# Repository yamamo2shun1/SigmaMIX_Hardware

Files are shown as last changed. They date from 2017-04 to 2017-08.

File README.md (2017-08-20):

# SigmaMIX
The SigmaMIX is a DSP/BLE board for Turntablist/Portablist, and it's an Open Source Hardware.

# Firmware/Software Repository
* [SigmaMIX Firmware for SiLabs BGM113](https://github.com/tkrworks/SigmaMIX_Firmware)  
* [SigmaMIX Remote App for Android](https://github.com/tkrworks/SigmaMIX_Remote)

**I made sure to be able to control two ADAU1701 from the BGM113 via I2C on June 7 2017!!!**

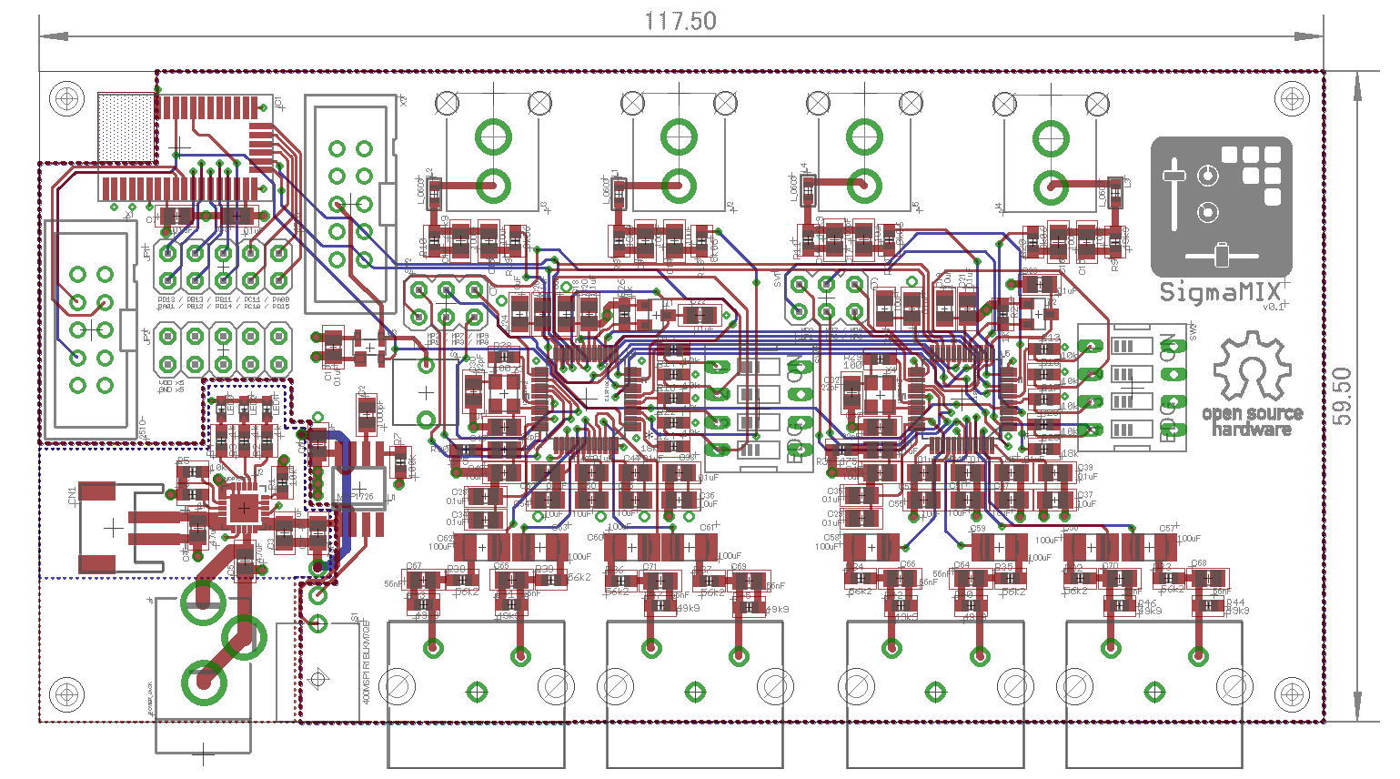
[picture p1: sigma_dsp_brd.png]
SigmaMIX Board

SigmaMIX PCB

## Test Video
[Delay Test](https://www.instagram.com/p/BXrRHsZBKkE/)  
[Effect and Scratch DEMO](https://www.instagram.com/p/BXWzQCQBJe1/)  
[Phono and Line inputs Mix and Fader Cutting Test](https://www.instagram.com/p/BV4aKTPhfiU/)  
[3-Band EQ Test via BLE](https://www.instagram.com/p/BVq-pJHB9hm/)  
[Phono EQ Test](https://www.instagram.com/p/BVVsefTBJXY/)  
[Beat and Sine Tone Test](https://www.instagram.com/p/BVFF-J9hF4o/)  
[First Scratch Test](https://www.instagram.com/p/BUi_Y2OhvBm/)  

## SPEC
* DSP: ANALOG DEVICES SigmaDSP [ADAU1701](http://www.analog.com/jp/products/processors-dsp/sigmadsp-audio-processors/adau1701.html) x2
* BLE: Silicon Labs [BGM113](http://jp.silabs.com/products/wireless/bluetooth/bluetooth-low-energy-modules/bgm113-bluetooth-low-energy-module)
* Audio: RCA Input x4 and RCA Output x8
* Power: ONLY 5-16V input [MIC39101](http://www.microchip.com/wwwproducts/en/MIC39100).
* Size: 112.0mm x 59.5mm

## HARDWARE LICENSE
<br /><span xmlns:dct="http://purl.org/dc/terms/" property="dct:title">SigmaMIX</span> by <span xmlns:cc="http://creativecommons.org/ns#" property="cc:attributionName">Shunichi Yamamoto</span> is licensed under a <a rel="license" href="http://creativecommons.org/licenses/by-sa/4.0/">Creative Commons Attribution-ShareAlike 4.0 International License</a>.

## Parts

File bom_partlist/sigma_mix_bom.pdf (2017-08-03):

Part | Value | Package | Description | Digikey
C1 | 1uF | 2012 | Multilayer Ceramic Capacitor | 490-1691-1-ND
C2 | 10uF | 2012 | Tantalum Capacitor | 478-8115-1-ND
C3 | 0.1uF | 2012 | Multilayer Ceramic Capacitor | 490-1683-6-ND
C4 | 0.1uF | 2012 | Multilayer Ceramic Capacitor | 490-1683-6-ND
C5 | 0.1uF | 2012 | Multilayer Ceramic Capacitor | 490-1683-6-ND
C6 | 10uF | 2012 | Tantalum Capacitor | 478-8115-1-ND
C7 | 0.1uF | 2012 | Multilayer Ceramic Capacitor | 490-1683-6-ND
C8 | 0.1uF | 2012 | Multilayer Ceramic Capacitor | 490-1683-6-ND
C9 | 100uF | 3528 | Tantalum Capacitor | 718-1313-1-ND
C10 | 10uF | 2012 | Multilayer Ceramic Capacitor | 490-3905-1-ND
C11 | 10uF | 2012 | Tantalum Capacitor | 478-8115-1-ND
C12 | 0.1uF | 2012 | Multilayer Ceramic Capacitor | 490-1683-6-ND
C13 | 0.1uF | 2012 | Multilayer Ceramic Capacitor | 490-1683-6-ND
C14 | 0.1uF | 2012 | Multilayer Ceramic Capacitor | 490-1683-6-ND
C15 | 10uF | 2012 | Tantalum Capacitor | 478-8115-1-ND
C16 | 0.1uF | 2012 | Multilayer Ceramic Capacitor | 490-1683-6-ND
C17 | 0.1uF | 2012 | Multilayer Ceramic Capacitor | 490-1683-6-ND
C18 | 10uF | 2012 | Multilayer Ceramic Capacitor | 490-3905-1-ND
C19 | 0.1uF | 2012 | Multilayer Ceramic Capacitor | 490-1683-6-ND
C20 | 10uF | 2012 | Multilayer Ceramic Capacitor | 490-3905-1-ND
C21 | 0.1uF | 2012 | Multilayer Ceramic Capacitor | 490-1683-6-ND
C22 | 10uF | 2012 | Multilayer Ceramic Capacitor | 490-3905-1-ND
C23 | 100uF | 3528 | Tantalum Capacitor | 718-1313-1-ND
C24 | 56nF | 2012 | Multilayer Ceramic Capacitor | 490-1662-1-ND
C25 | 3.3nF | 2012 | Multilayer Ceramic Capacitor | 399-1153-1-ND
C26 | 10uF | 2012 | Multilayer Ceramic Capacitor | 490-3905-1-ND
C27 | 100pF | 2012 | Multilayer Ceramic Capacitor | 490-1615-1-ND
C28 | 100pF | 2012 | Multilayer Ceramic Capacitor | 490-1615-1-ND
C29 | 100uF | 3528 | Tantalum Capacitor | 718-1313-1-ND
C30 | 100uF | 3528 | Tantalum Capacitor | 718-1313-1-ND
C31 | 56nF | 2012 | Multilayer Ceramic Capacitor | 490-1662-1-ND
C32 | 56nF | 2012 | Multilayer Ceramic Capacitor | 490-1662-1-ND
C33 | 56nF | 2012 | Multilayer Ceramic Capacitor | 490-1662-1-ND
C34 | 56nF | 2012 | Multilayer Ceramic Capacitor | 490-1662-1-ND
C35 | 0.1uF | 2012 | Multilayer Ceramic Capacitor | 490-1683-6-ND
C36 | 0.1uF | 2012 | Multilayer Ceramic Capacitor | 490-1683-6-ND
C37 | 10uF | 2012 | Tantalum Capacitor | 478-8115-1-ND
C38 | 0.1uF | 2012 | Multilayer Ceramic Capacitor | 490-1683-6-ND

C39 | 100uF | 3528 | Tantalum Capacitor | 718-1313-1-ND
C40 | 10uF | 2012 | Multilayer Ceramic Capacitor | 490-3905-1-ND
C41 | 10uF | 2012 | Tantalum Capacitor | 478-8115-1-ND
C42 | 0.1uF | 2012 | Multilayer Ceramic Capacitor | 490-1683-6-ND
C43 | 0.1uF | 2012 | Multilayer Ceramic Capacitor | 490-1683-6-ND
C44 | 0.1uF | 2012 | Multilayer Ceramic Capacitor | 490-1683-6-ND
C45 | 10uF | 2012 | Tantalum Capacitor | 478-8115-1-ND
C46 | 0.1uF | 2012 | Multilayer Ceramic Capacitor | 490-1683-6-ND
C47 | 0.1uF | 2012 | Multilayer Ceramic Capacitor | 490-1683-6-ND
C48 | 10uF | 2012 | Multilayer Ceramic Capacitor | 490-3905-1-ND
C49 | 0.1uF | 2012 | Multilayer Ceramic Capacitor | 490-1683-6-ND
C50 | 10uF | 2012 | Multilayer Ceramic Capacitor | 490-3905-1-ND
C51 | 0.1uF | 2012 | Multilayer Ceramic Capacitor | 490-1683-6-ND
C52 | 10uF | 2012 | Multilayer Ceramic Capacitor | 490-3905-1-ND
C53 | 100uF | 3528 | Tantalum Capacitor | 718-1313-1-ND
C54 | 56nF | 2012 | Multilayer Ceramic Capacitor | 490-1662-1-ND
C55 | 3.3nF | 2012 | Multilayer Ceramic Capacitor | 399-1153-1-ND
C56 | 10uF | 2012 | Multilayer Ceramic Capacitor | 490-3905-1-ND
C57 | 100pF | 2012 | Multilayer Ceramic Capacitor | 490-1615-1-ND
C58 | 100pF | 2012 | Multilayer Ceramic Capacitor | 490-1615-1-ND
C59 | 100uF | 3528 | Tantalum Capacitor | 718-1313-1-ND
C60 | 100uF | 3528 | Tantalum Capacitor | 718-1313-1-ND
C61 | 56nF | 2012 | Multilayer Ceramic Capacitor | 490-1662-1-ND
C62 | 56nF | 2012 | Multilayer Ceramic Capacitor | 490-1662-1-ND
C63 | 56nF | 2012 | Multilayer Ceramic Capacitor | 490-1662-1-ND
C64 | 56nF | 2012 | Multilayer Ceramic Capacitor | 490-1662-1-ND
IC1 | BGM113 | LGA Module | Bluetooth Module | 336-3817-1-ND
J1 | DC_JACK | Through Hole | Power Connector | | 未実装
J2 | RCA2_JACK | Through Hole | Audio Connector | CP-1435-ND | 未実装
J3 | RCA_JACK | Through Hole | Audio Connector | CP-1419-ND | 未実装
J4 | RCA_JACK | Through Hole | Audio Connector | CP-1420-ND | 未実装
J5 | RCA2_JACK | Through Hole | Audio Connector | CP-1435-ND | 未実装
J6 | RCA2_JACK | Through Hole | Audio Connector | CP-1435-ND | 未実装
J7 | RCA_JACK | Through Hole | Audio Connector | CP-1419-ND | 未実装
J8 | RCA_JACK | Through Hole | Audio Connector | CP-1420-ND | 未実装
J9 | RCA2_JACK | Through Hole | Audio Connector | CP-1435-ND | 未実装
JP1 | 2x5 | Through Hole | Pin Header | | 未実装
JP2 | 2x6 | Through Hole | Pin Header | | 未実装
JP3 | 2x6 | Through Hole | Pin Header | 未実装

L1 | 600ohm@100MHz | 1608 | Ferrite Beads | 490-14396-1-ND
L2 | 600ohm@100MHz | 1608 | Ferrite Beads | 490-14396-1-ND
L3 | 600ohm@100MHz | 1608 | Ferrite Beads | 490-14396-1-ND
L4 | 600ohm@100MHz | 1608 | Ferrite Beads | 490-14396-1-ND
LED1 | GREEN | 3216 | LED | 67-1002-1-ND
LED2 | RED | 3216 | LED | 67-1003-1-ND
R1 | 100k | 1608 | Resistor | P100KHCT-ND
R2 | 562 | 1608 | Resistor | P562HCT-ND
R3 | 1k | 1608 | Resistor | P1.00KHCT-ND
R4 | 10k | 1608 | Resistor | P10.0KHCT-ND
R5 | 56R2 | 1608 | Resistor | P56.2HCT-ND
R6 | 8k06 | 1608 | Resistor | P8.06KHCT-ND
R7 | 56R2 | 1608 | Resistor | P56.2HCT-ND
R8 | 8k06 | 1608 | Resistor | P8.06KHCT-ND
R9 | 56R2 | 1608 | Resistor | P56.2HCT-ND
R10 | 49k9 | 1608 | Resistor | P49.9KHCT-ND
R11 | 49k9 | 1608 | Resistor | P49.9KHCT-ND
R12 | 18k | 1608 | Resistor | P18.0KHCT-ND
R13 | 475 | 1608 | Resistor | P475HCT-ND
R14 | 56R2 | 1608 | Resistor | P56.2HCT-ND
R15 | 49k9 | 1608 | Resistor | P49.9KHCT-ND
R16 | 49k9 | 1608 | Resistor | P49.9KHCT-ND
R17 | 49k9 | 1608 | Resistor | P49.9KHCT-ND
R18 | 49k9 | 1608 | Resistor | P49.9KHCT-ND
R19 | 10k | 1608 | Resistor | P10.0KHCT-ND
R20 | 10k | 1608 | Resistor | P10.0KHCT-ND
R21 | 10k | 1608 | Resistor | P10.0KHCT-ND
R22 | 10k | 1608 | Resistor | P10.0KHCT-ND
R23 | 0 | 1608 | Resistor | P0.0ACT-ND
R24 | 1k | 1608 | Resistor | P1.00KHCT-ND
R25 | 56R2 | 1608 | Resistor | P56.2HCT-ND
R26 | 8k06 | 1608 | Resistor | P8.06KHCT-ND
R27 | 56R2 | 1608 | Resistor | P56.2HCT-ND
R28 | 8k06 | 1608 | Resistor | P8.06KHCT-ND
R29 | 56R2 | 1608 | Resistor | P56.2HCT-ND
R30 | 49k9 | 1608 | Resistor | P49.9KHCT-ND
R31 | 49k9 | 1608 | Resistor | P49.9KHCT-ND
R32 | 18k | 1608 | Resistor | P18.0KHCT-ND
R33 | 475 | 1608 | Resistor | P475HCT-ND

R34 | 56R2 | 1608 | Resistor | P56.2HCT-ND
R35 | 49k9 | 1608 | Resistor | P49.9KHCT-ND
R36 | 49k9 | 1608 | Resistor | P49.9KHCT-ND
R37 | 49k9 | 1608 | Resistor | P49.9KHCT-ND
R38 | 49k9 | 1608 | Resistor | P49.9KHCT-ND
R39 | 10k | 1608 | Resistor | P10.0KHCT-ND
R40 | 10k | 1608 | Resistor | P10.0KHCT-ND
R41 | 10k | 1608 | Resistor | P10.0KHCT-ND
R42 | 10k | 1608 | Resistor | P10.0KHCT-ND
R43 | 562 | 1608 | Resistor | P562HCT-ND
S1 | ROCKER SW | Through Hole | Switch | EG4328-ND | 未実装
S2 | TACTILE SW | Through Hole | Switch | EG4328-ND | 未実装
SV1 | 2x3 | Through Hole | Pin Header | | 未実装
SV2 | 2x3 | Through Hole | Pin Header | | 未実装
SW1 | DIP SW | Through Hole | Switch | SW1194-ND | 未実装
SW2 | DIP SW | Through Hole | Switch | SW1194-ND | 未実装
T1 | PNP | SOT-23 | Transistor | ZXTP25040DFHCT-ND
T2 | PNP | SOT-23 | Transistor | ZXTP25040DFHCT-ND
U1 | MIC39101 | SOIC8 | Power Regulator IC | 576-1782-5-ND
U2 | ADM811 | SOT-143 | Reset IC | ADM811TARTZ-REEL7CT-ND
U3 | ADAU1701 | LQFP48 | DSP IC | ADAU1701JSTZ-RLCT-ND
U4 | ADAU1701 | LQFP48 | DSP IC | ADAU1701JSTZ-RLCT-ND
X1 | SWD Interface | Through Hole | Connector | MHC20K-ND | 未実装
X2 | USBi | Through Hole | Connector | MHC10K-ND | 未実装
Y1 | 12.28MHz | SMD | Crystal Oscillator | SER4107CT-ND

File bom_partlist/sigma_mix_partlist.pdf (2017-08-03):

Part | Value | Package | Num | Description | Digikey
C3, C4, C5, C7, C8, C12, C13, C14, C16, C17, C19, C21,C35, C36, C38, C42, C43, C44, C46, C47, C49, C51 | 0.1uF | 2012 | 22 | Multilayer Ceramic Capacitor | 490-1683-6-ND
C27, C28, C57, C58 | 100pF | 2012 | 4 | Multilayer Ceramic Capacitor | 490-1615-1-ND
C9, C23, C29, C30, C39, C53, C59, C60 | 100uF | 3528 | 8 | Tantalum Capacitor | 718-1313-1-ND
C2, C6, C11, C15, C37, C41, C45 | 10uF | 2012 | 7 | Tantalum Capacitor | 478-8115-1-ND
C10, C18, C20, C22, C26, C40, C48, C50, C52, C56 | 10uF | 2012 | 10 | Multilayer Ceramic Capacitor | 490-3905-1-ND
C1 | 1uF | 2012 | 1 | Multilayer Ceramic Capacitor | 490-1691-1-ND
C25, C55 | 3.3nF | 2012 | 2 | Multilayer Ceramic Capacitor | 399-1153-1-ND
C24, C31, C32, C33, C34, C54, C61, C62, C63, C64 | 56nF | 2012 | 10 | Multilayer Ceramic Capacitor | 490-1662-1-ND
IC1 | BGM113 | LGA Module | 1 | Bluetooth Module | 336-3817-1-ND
J1 | DC_JACK | Through Hole | 1 | Power Connector | | 未実装
J2, J5, J6, J9 | RCA2_JACK | Through Hole | 4 | Audio Connector | CP-1435-ND | 未実装
J3, J4, J7, J8 | RCA_JACK | Through Hole | 2 | Audio Connector | CP-1419-ND | 未実装
JP1 | 2x5 | Through Hole | 1 | Pin Header | | 未実装
JP2, JP3 | 2x6 | Through Hole | 2 | Pin Header | | 未実装
L1, L2, L3, L4 | 600ohm@100MHz | 1608 | 4 | Ferrite Beads | 490-14396-1-ND
LED1 | GREEN | 3216 | 1 | LED | 67-1002-1-ND
LED2 | RED | 3216 | 1 | LED | 67-1003-1-ND
R1 | 100k | 1608 | 1 | Resistor | P100KHCT-ND
R23 | 0 | 1608 | 1 | Resistor | P0.0ACT-ND
R13, R33 | 475 | 1608 | 2 | Resistor | P475HCT-ND
R2, R43 | 562 | 1608 | 2 | Resistor | P562HCT-ND
R4, R19, R20, R21, R22, R39, R40, R41, R42 | 10k | 1608 | 9 | Resistor | P10.0KHCT-ND
R12, R32 | 18k | 1608 | 2 | Resistor | P18.0KHCT-ND
R3, R24 | 1k | 1608 | 2 | Resistor | P1.00KHCT-ND
R10, R11, R15, R16, R17, R18, R30, R31, R35, R36, R37, R38 | 49k9 | 1608 | 12 | Resistor | P49.9KHCT-ND
R5, R7, R9, R14, R25, R27, R29, R34 | 56R2 | 1608 | 8 | Resistor | P56.2HCT-ND
R6, R8, R26, R28 | 8k06 | 1608 | 4 | Resistor | P8.06KHCT-ND
S1 | ROCKER SW | Through Hole | 1 | Switch | EG4328-ND | 未実装
S2 | TACTILE SW | Through Hole | 1 | Switch | EG4328-ND | 未実装
SV1, SV2 | 2x3 | Through Hole | 2 | Pin Header | | 未実装
SW1, SW2 | DIP SW | Through Hole | 2 | Switch | SW1194-ND | 未実装
T1, T2 | PNP | SOT-23 | 2 | Transistor | ZXTP25040DFHCT-ND
U1 | MIC39101 | SOIC8 | 1 | Power Regulator IC | 576-1782-5-ND
U2 | ADM811 | SOT-143 | 1 | Reset IC | ADM811TARTZ-REEL7CT-ND
U3, U4 | ADAU1701 | LQFP48 | 2 | DSP IC | ADAU1701JSTZ-RLCT-ND
X1 | SWD Interface | Through Hole | 1 | Connector | MHC20K-ND | 未実装
X2 | USBi | Through Hole | 1 | Connector | MHC10K-ND | 未実装
Y1 | 12.28MHz | SMD | 1 | Crystal Oscillator | SER4107CT-ND

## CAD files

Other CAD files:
jig/SigmaMIX_Jig.dwg

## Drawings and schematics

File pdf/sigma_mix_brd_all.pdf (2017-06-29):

112.00

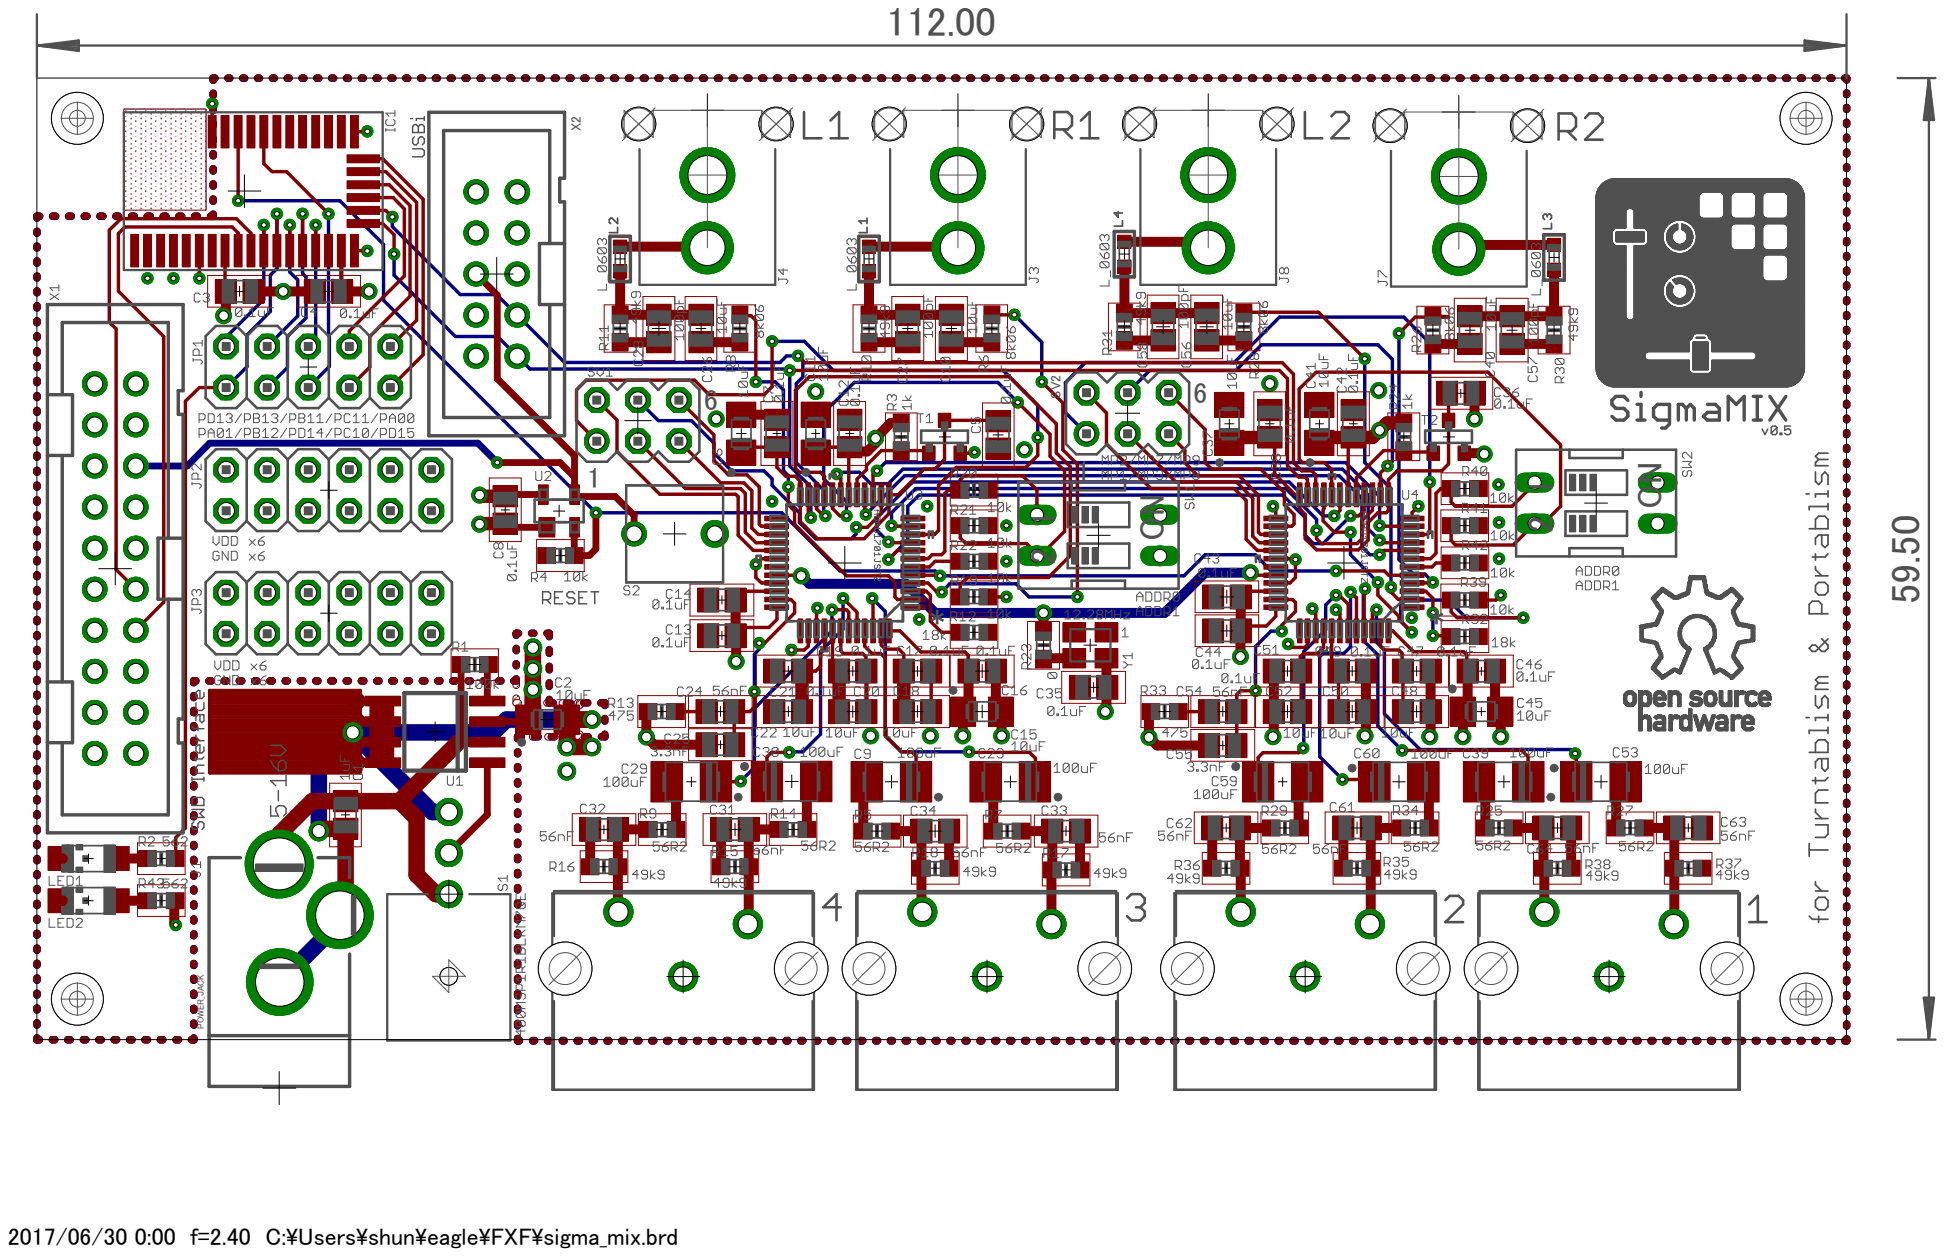
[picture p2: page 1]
POWER_JACK

2017/06/30 0:00 f=2.40 C:\Users\shun\eagle\FXF\sigma_mix.brd

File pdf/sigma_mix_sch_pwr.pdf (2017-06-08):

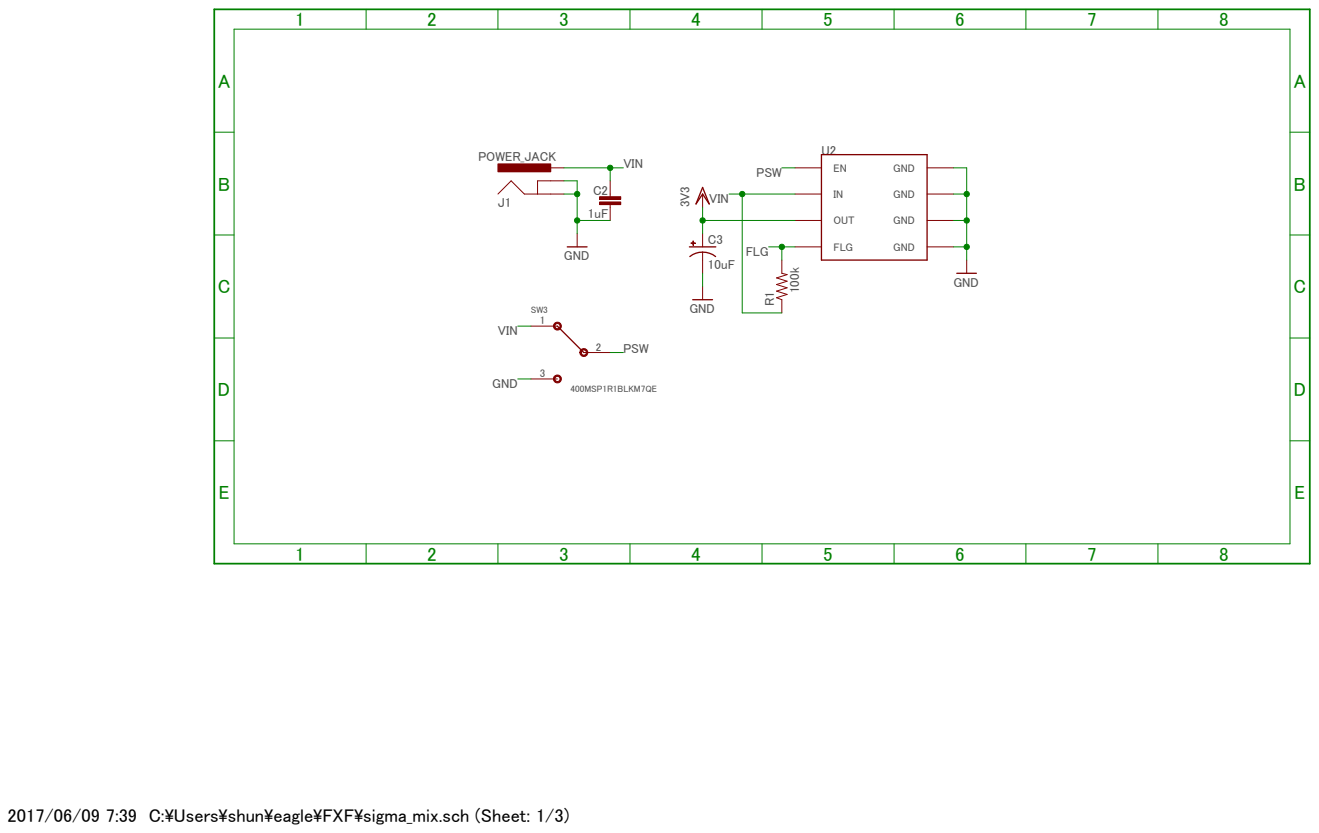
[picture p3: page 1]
GND; 400MSP1R1BLKM7QE; POWER_JACK; 3V3 GND; OUT; FLG; VIN; PSW

2017/06/09 7:39 C:\Users\shun\eagle\FXF\sigma_mix.sch (Sheet: 1/3)

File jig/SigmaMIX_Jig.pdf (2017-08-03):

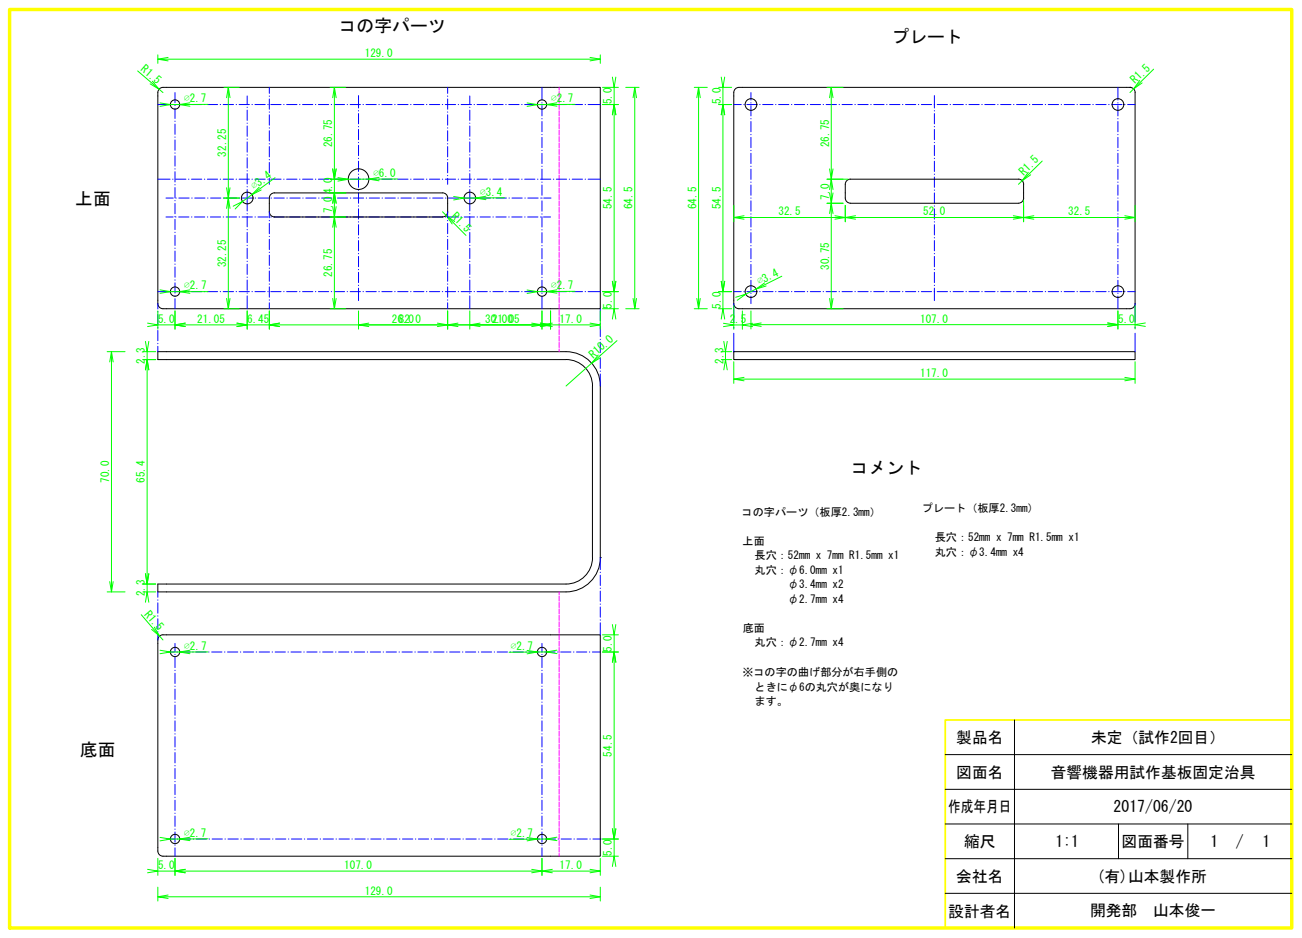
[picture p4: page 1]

製品名 | 未定（試作2回目）

図面名 | 音響機器用試作基板固定治具

作成年月日 | 2017/06/20

縮尺 | 1:1 | 図面番号 | 1 / 1

会社名 | (有)山本製作所

設計者名 | 開発部　山本俊一

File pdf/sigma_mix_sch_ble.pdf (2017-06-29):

A

A

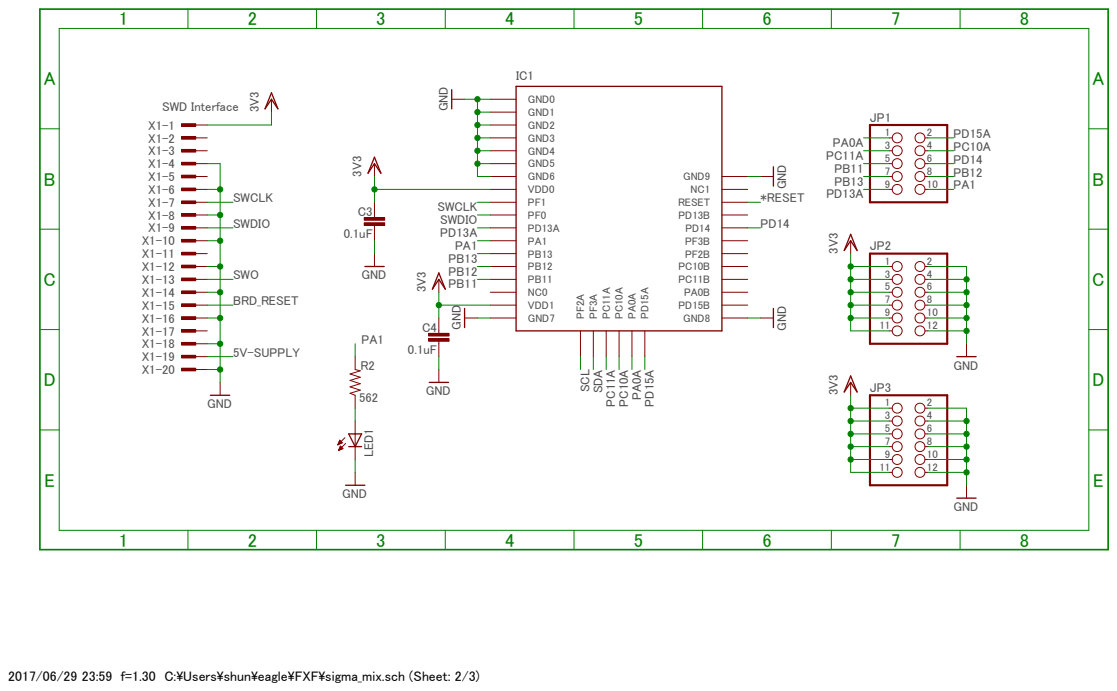
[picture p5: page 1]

2017/06/29 23:59 f=1.30 C:\Users\shun\eagle\FXF\sigma_mix.sch (Sheet: 2/3)

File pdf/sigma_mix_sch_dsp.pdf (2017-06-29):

A

A

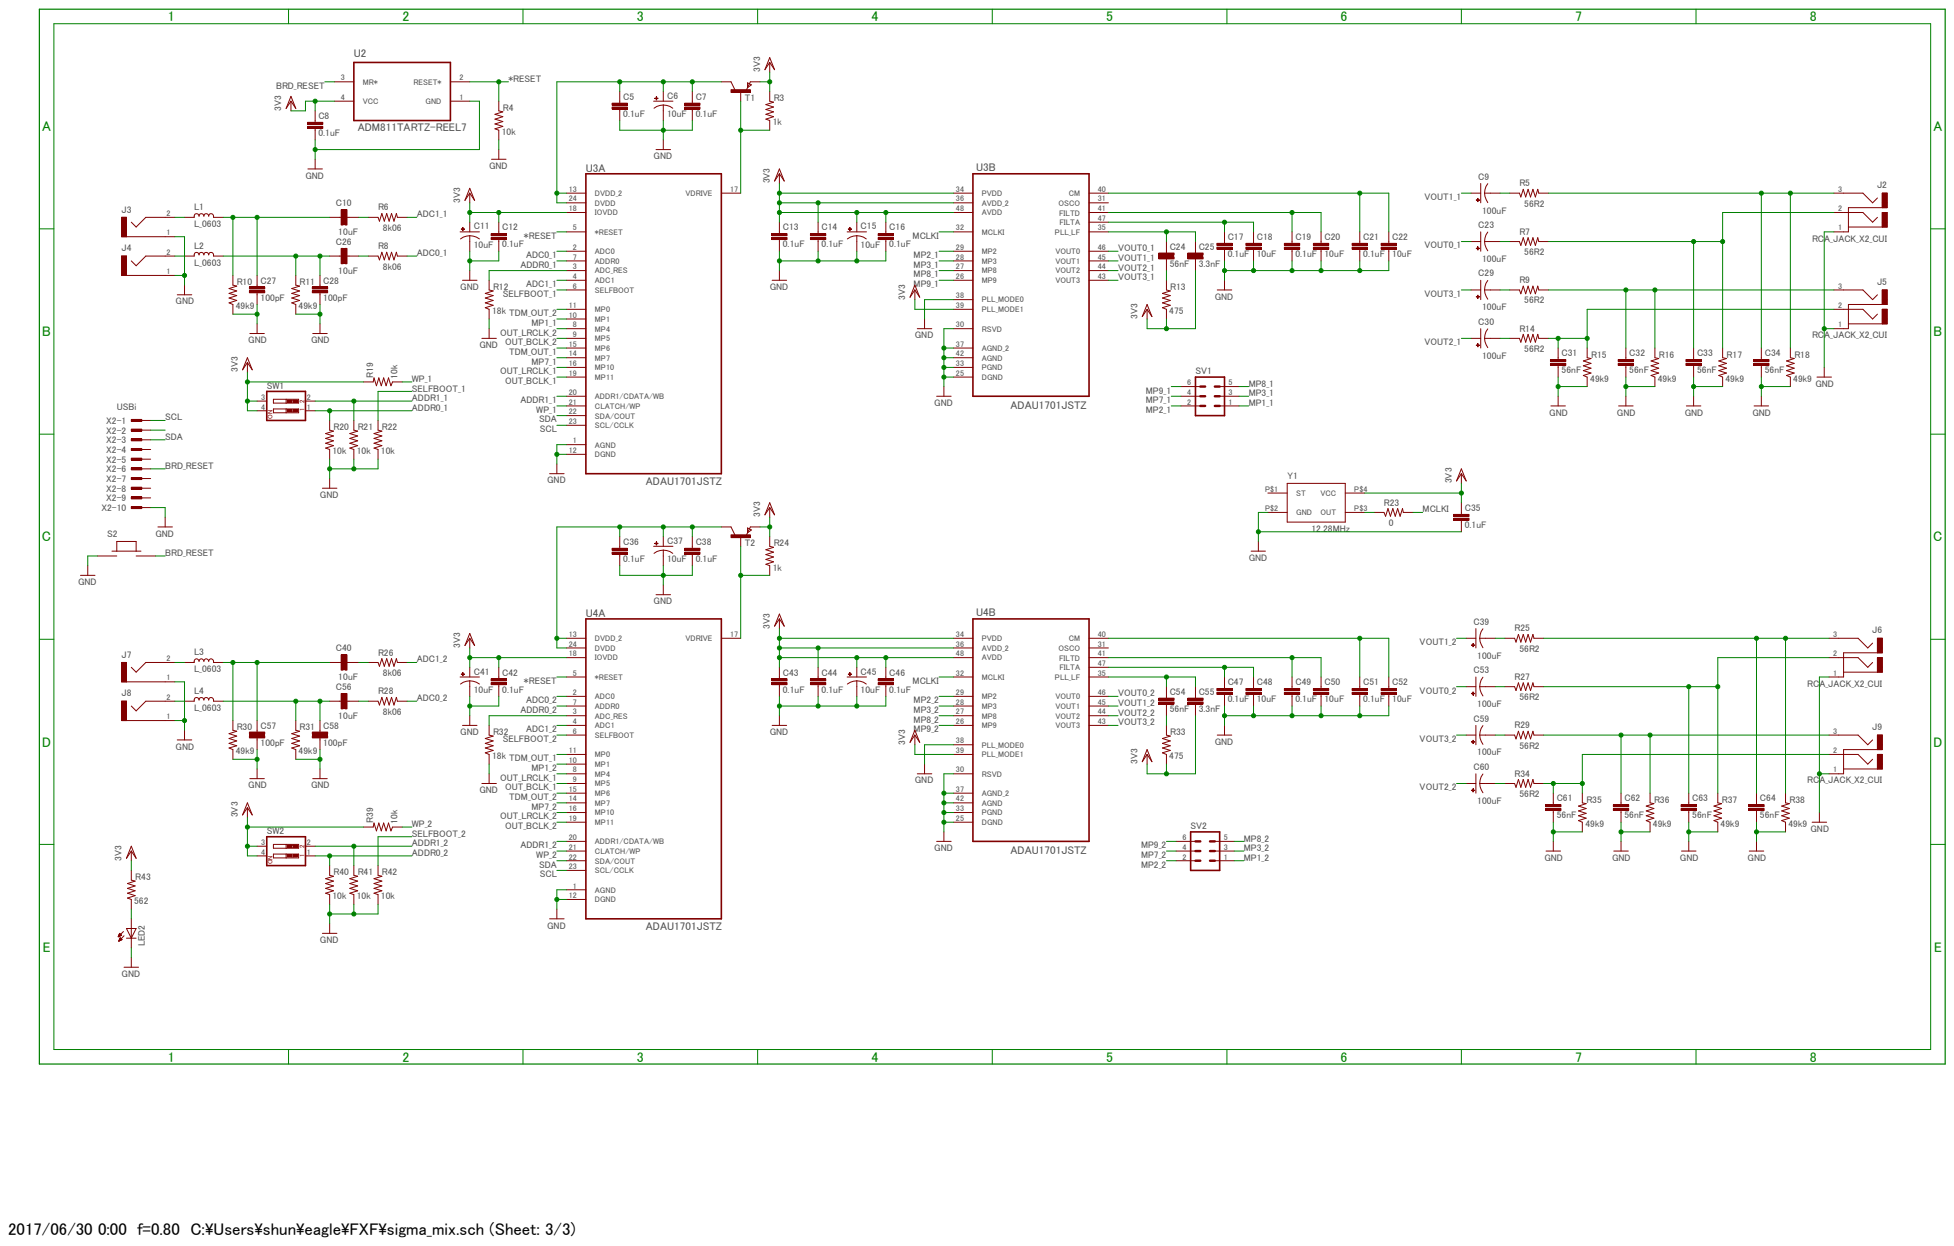
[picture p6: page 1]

2017/06/30 0:00 f=0.80 C:\Users\shun\eagle\FXF\sigma_mix.sch (Sheet: 3/3)

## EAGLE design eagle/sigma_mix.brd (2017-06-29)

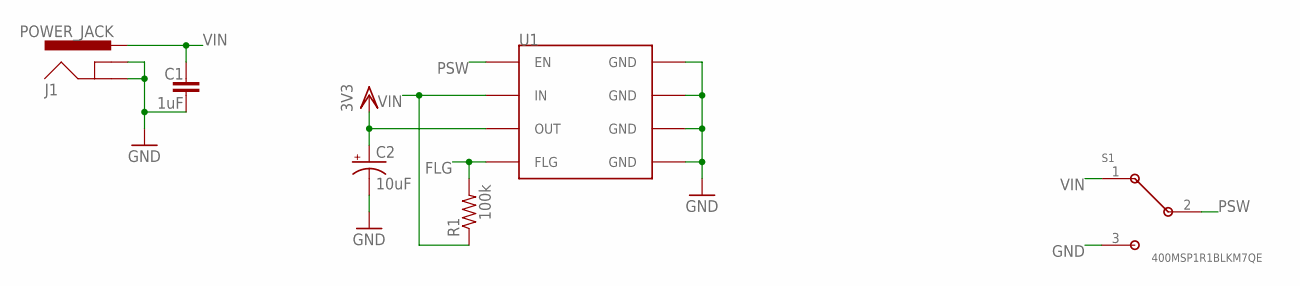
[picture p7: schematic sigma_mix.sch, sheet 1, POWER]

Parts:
C1: 1uF; C2012
C2: 10uF; R/2012-12R
J1: POWER_JACK; POWER_JACK_PTH_LOCK
R1: 100k; 0603-RES
S1: 400MSP1R1BLKM7QE
U1: MIC39100; SOIC8

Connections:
FLG: R1.2, U1.4 (FLG)
GND: C1.2, C2.-, J1.GND, J1.GNDBREAK, S1.3, U1.5 (GND), U1.6 (GND), U1.7 (GND), U1.8 (GND); also elsewhere on the board
PSW: S1.2, U1.1 (EN)
VDD: C2.+, U1.3 (OUT); also elsewhere on the board
VIN: C1.1, J1.PWR, R1.1, S1.1, U1.2 (IN)

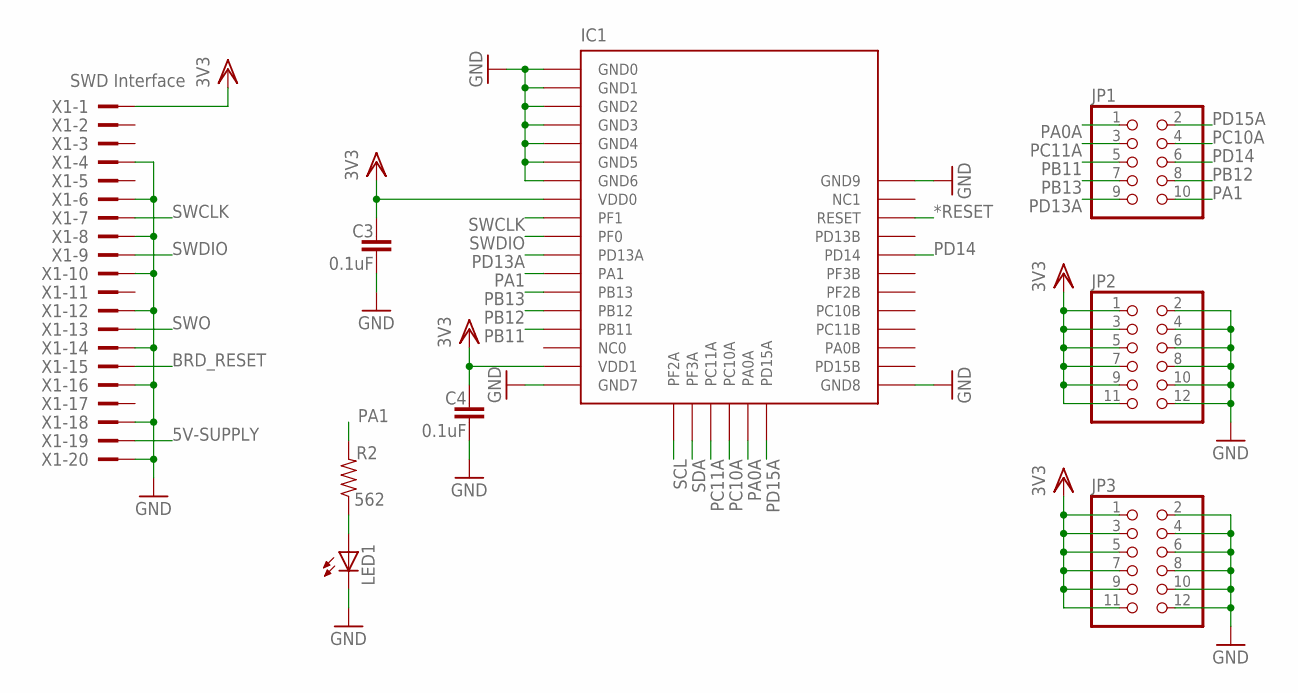
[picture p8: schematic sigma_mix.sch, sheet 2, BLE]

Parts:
C3, C4: 0.1uF; C2012
IC1: BGM113; BLE113
JP1: PINHD-2X5; 2X05
JP2, JP3: PINHD-2X6; 2X06
LED1: LEDCHIPLED_1206; CHIPLED_1206
R2: 562; 0603-RES
X1: SWD Interface; PAK100/2500-20

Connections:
5V-SUPPLY: X1.19
*RESET: IC1.P$34 (RESET); also elsewhere on the board
BRD_RESET: X1.15; also elsewhere on the board
GND: C3.2, C4.2, IC1.P$1 (GND0), IC1.P$2 (GND1), IC1.P$3 (GND2), IC1.P$4 (GND3), IC1.P$5 (GND4), IC1.P$6 (GND5), IC1.P$7 (GND6), IC1.P$18 (GND7), IC1.P$25 (GND8), IC1.P$36 (GND9), JP2.2, JP2.4, JP2.6, JP2.8, JP2.10, JP2.12, JP3.2, JP3.4, JP3.6, JP3.8, JP3.10, JP3.12, LED1.C, X1.4, X1.6, X1.8, X1.10, X1.12, X1.14, X1.16, X1.18, X1.20; also elsewhere on the board
unnamed: LED1.A, R2.1
PA0A: IC1.P$23 (PA0A), JP1.1
PA1: IC1.P$12 (PA1), JP1.10, R2.2
PB11: IC1.P$15 (PB11), JP1.5
PB12: IC1.P$14 (PB12), JP1.8
PB13: IC1.P$13 (PB13), JP1.7
PC10A: IC1.P$22 (PC10A), JP1.4
PC11A: IC1.P$21 (PC11A), JP1.3
PD13A: IC1.P$11 (PD13A), JP1.9
PD14: IC1.P$32 (PD14), JP1.6
PD15A: IC1.P$24 (PD15A), JP1.2
SCL: IC1.P$19 (PF2A); also elsewhere on the board
SDA: IC1.P$20 (PF3A); also elsewhere on the board
SWCLK: IC1.P$9 (PF1), X1.7
SWDIO: IC1.P$10 (PF0), X1.9
SWO: X1.13
VDD: C3.1, C4.1, IC1.P$8 (VDD0), IC1.P$17 (VDD1), JP2.1, JP2.3, JP2.5, JP2.7, JP2.9, JP2.11, JP3.1, JP3.3, JP3.5, JP3.7, JP3.9, JP3.11, X1.1; also elsewhere on the board

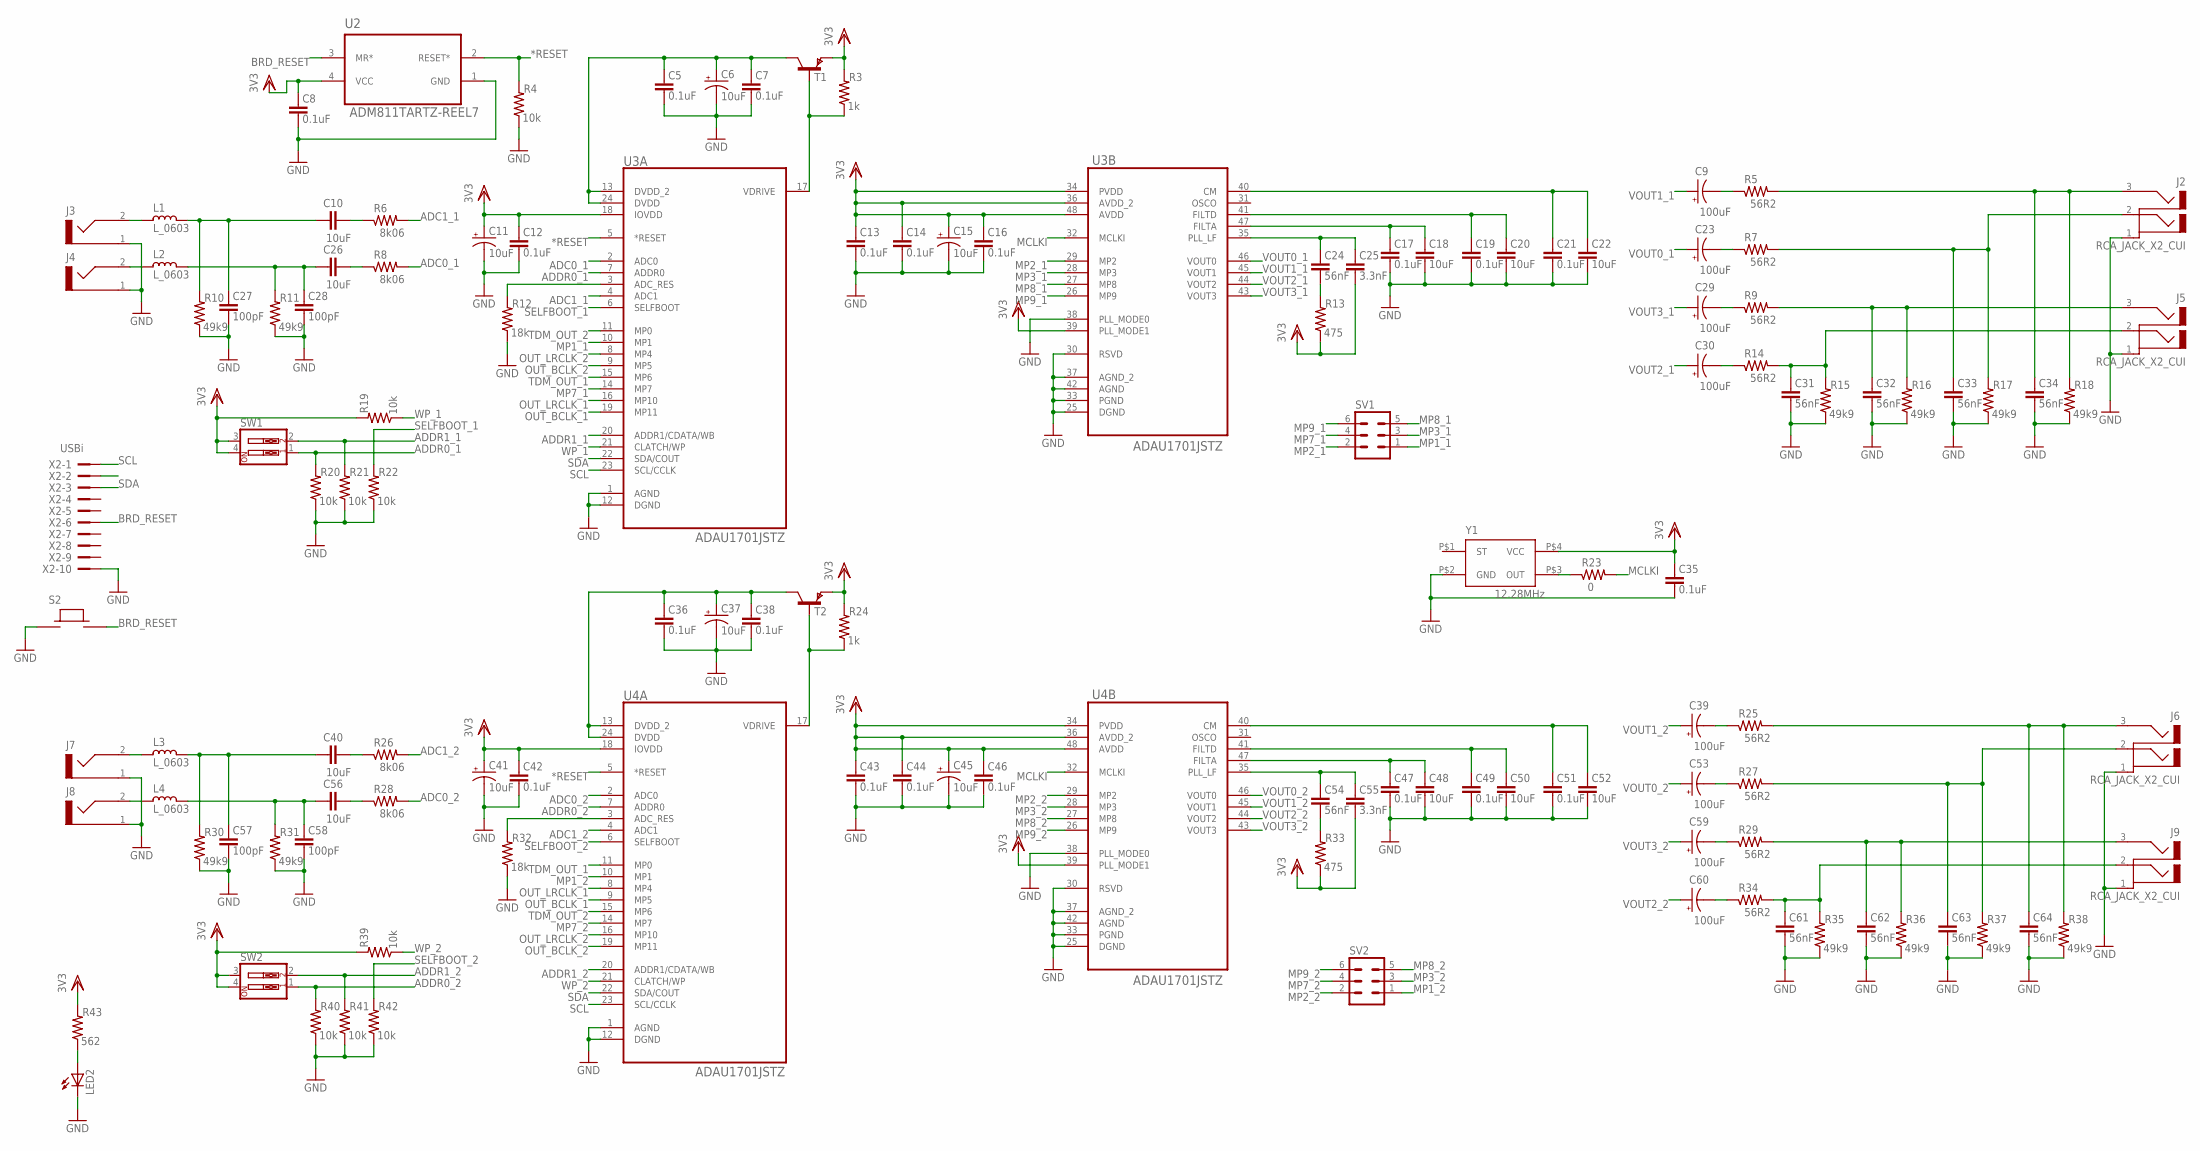
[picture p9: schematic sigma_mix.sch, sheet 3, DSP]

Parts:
C5, C7, C8, C12, C13, C14, C16, C17, C19, C21, C35, C36, C38, C42, C43, C44, C46, C47, C49, C51: 0.1uF; C2012
C6, C11, C15, C37, C41, C45: 10uF; R/2012-12R
C9, C23, C29, C30, C39, C53, C59, C60: 100uF; B/3528-21R
C10, C18, C20, C22, C26, C40, C48, C50, C52, C56: 10uF; C2012
C24, C31, C32, C33, C34, C54, C61, C62, C63, C64: 56nF; C2012
C25, C55: 3.3nF; C2012
C27, C28, C57, C58: 100pF; C2012
J2, J5, J6, J9: RCA_JACK_X2_CUI
J3, J4, J7, J8: RCA_JACK_CUI
L1, L2, L3, L4: L_0603; L0603
LED2: LEDCHIPLED_1206; CHIPLED_1206
R3, R24: 1k; 0603-RES
R4, R19, R20, R21, R22, R39, R40, R41, R42: 10k; 0603-RES
R5, R7, R9, R14, R25, R27, R29, R34: 56R2; 0603-RES
R6, R8, R26, R28: 8k06; 0603-RES
R10, R11, R15, R16, R17, R18, R30, R31, R35, R36, R37, R38: 49k9; 0603-RES
R12, R32: 18k; 0603-RES
R13, R33: 475; 0603-RES
R23: 0; 0603-RES
R43: 562; 0603-RES
S2: OMRON_B3M
SV1, SV2: MA03-2
SW1, SW2: SW_DIP-2; EDG-02
T1, T2: PNPSOT23; SOT-23
U2: ADM811TARTZ-REEL7; SOT143P290X130-4N
U3, U4: ADAU1701JSTZ; QFP50P900X900X160-48N
X2: USBi; PAK100/2500-10
Y1: 12.28MHz; SG-210

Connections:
*RESET: R4.2, U2.2 (RESET*), U3.5 (*RESET), U4.5 (*RESET); also elsewhere on the board
ADC0_1: R8.2, U3.2 (ADC0)
ADC0_2: R28.2, U4.2 (ADC0)
ADC1_1: R6.2, U3.4 (ADC1)
ADC1_2: R26.2, U4.4 (ADC1)
ADDR0_1: R20.2, SW1.1, U3.7 (ADDR0)
ADDR0_2: R40.2, SW2.1, U4.7 (ADDR0)
ADDR1_1: R21.2, SW1.2, U3.20 (ADDR1/CDATA/WB)
ADDR1_2: R41.2, SW2.2, U4.20 (ADDR1/CDATA/WB)
BRD_RESET: S2.P$2, U2.3 (MR*), X2.6; also elsewhere on the board
DVDD: C5.1, C6.+, C7.1, T1.1 (C), U3.13 (DVDD_2), U3.24 (DVDD)
GND: C5.2, C6.-, C7.2, C8.2, C11.-, C12.2, C13.2, C14.2, C15.-, C16.2, C17.2, C18.2, C19.2, C20.2, C21.2, C22.2, C27.2, C28.2, C31.2, C32.2, C33.2, C34.2, C35.2, C36.2, C37.-, C38.2, C41.-, C42.2, C43.2, C44.2, C45.-, C46.2, C47.2, C48.2, C49.2, C50.2, C51.2, C52.2, C57.2, C58.2, C61.2, C62.2, C63.2, C64.2, J2.1, J3.1, J4.1, J5.1, J6.1, J7.1, J8.1, J9.1, LED2.C, R4.1, R10.1, R11.1, R12.1, R15.1, R16.1, R17.1, R18.1, R20.1, R21.1, R22.1, R30.1, R31.1, R32.1, R35.1, R36.1, R37.1, R38.1, R40.1, R41.1, R42.1, S2.P$1, U2.1 (GND), U3.1 (AGND), U3.12 (DGND), U3.25 (DGND), U3.30 (RSVD), U3.33 (PGND), U3.37 (AGND_2), U3.38 (PLL_MODE0), U3.42 (AGND), U4.1 (AGND), U4.12 (DGND), U4.25 (DGND), U4.30 (RSVD), U4.33 (PGND), U4.37 (AGND_2), U4.38 (PLL_MODE0), U4.42 (AGND), X2.10, Y1.P$2 (GND); also elsewhere on the board
MCLKI: R23.2, U3.32 (MCLKI), U4.32 (MCLKI)
MP1_1: SV1.1, U3.10 (MP1)
MP1_2: SV2.1, U4.10 (MP1)
MP2_1: SV1.2, U3.29 (MP2)
MP2_2: SV2.2, U4.29 (MP2)
MP3_1: SV1.3, U3.28 (MP3)
MP3_2: SV2.3, U4.28 (MP3)
MP7_1: SV1.4, U3.14 (MP7)
MP7_2: SV2.4, U4.14 (MP7)
MP8_1: SV1.5, U3.27 (MP8)
MP8_2: SV2.5, U4.27 (MP8)
MP9_1: SV1.6, U3.26 (MP9)
MP9_2: SV2.6, U4.26 (MP9)
unnamed: R3.1, T1.3 (B), U3.17 (VDRIVE)
unnamed: C24.2, R13.2
unnamed: C24.1, C25.1, U3.35 (PLL_LF)
unnamed: C17.1, C18.1, U3.47 (FILTA)
unnamed: R23.1, Y1.P$3 (OUT)
unnamed: C19.1, C20.1, U3.41 (FILTD)
unnamed: C21.1, C22.1, U3.40 (CM)
unnamed: R12.2, U3.3 (ADC_RES)
unnamed: LED2.A, R43.1
unnamed: C10.2, C27.1, L1.1, R10.2
unnamed: C10.1, R6.1
unnamed: C26.2, C28.1, L2.1, R11.2
unnamed: C26.1, R8.1
unnamed: C9.-, R5.1
unnamed: J3.2, L1.2
unnamed: C23.-, R7.1
unnamed: C29.-, R9.1
unnamed: C30.-, R14.1
unnamed: C31.1, J5.2, R14.2, R15.2
unnamed: C32.1, J5.3, R9.2, R16.2
unnamed: C33.1, J2.2, R7.2, R17.2
unnamed: C34.1, J2.3, R5.2, R18.2
unnamed: J4.2, L2.2
unnamed: R24.1, T2.3 (B), U4.17 (VDRIVE)
unnamed: C36.1, C37.+, C38.1, T2.1 (C), U4.13 (DVDD_2), U4.24 (DVDD)
unnamed: C54.2, R33.2
unnamed: C54.1, C55.1, U4.35 (PLL_LF)
unnamed: C47.1, C48.1, U4.47 (FILTA)
unnamed: C49.1, C50.1, U4.41 (FILTD)
unnamed: C51.1, C52.1, U4.40 (CM)
unnamed: R32.2, U4.3 (ADC_RES)
unnamed: C40.2, C57.1, L3.1, R30.2
unnamed: C40.1, R26.1
unnamed: C56.2, C58.1, L4.1, R31.2
unnamed: C56.1, R28.1
unnamed: C39.-, R25.1
unnamed: C53.-, R27.1
unnamed: C59.-, R29.1
unnamed: C60.-, R34.1
unnamed: C61.1, J9.2, R34.2, R35.2
unnamed: C62.1, J9.3, R29.2, R36.2
unnamed: C63.1, J6.2, R27.2, R37.2
unnamed: C64.1, J6.3, R25.2, R38.2
unnamed: J7.2, L3.2
unnamed: J8.2, L4.2
OUT_BCLK_1: U3.19 (MP11), U4.9 (MP5)
OUT_BCLK_2: U3.9 (MP5), U4.19 (MP11)
OUT_LRCLK_1: U3.16 (MP10), U4.8 (MP4)
OUT_LRCLK_2: U3.8 (MP4), U4.16 (MP10)
SCL: U3.23 (SCL/CCLK), U4.23 (SCL/CCLK), X2.1; also elsewhere on the board
SDA: U3.22 (SDA/COUT), U4.22 (SDA/COUT), X2.3; also elsewhere on the board
SELFBOOT_1: R22.2, U3.6 (SELFBOOT)
SELFBOOT_2: R42.2, U4.6 (SELFBOOT)
TDM_OUT_1: U3.15 (MP6), U4.11 (MP0)
TDM_OUT_2: U3.11 (MP0), U4.15 (MP6)
VDD: C8.1, C11.+, C12.1, C13.1, C14.1, C15.+, C16.1, C25.2, C35.1, C41.+, C42.1, C43.1, C44.1, C45.+, C46.1, C55.2, R3.2, R13.1, R19.2, R24.2, R33.1, R39.2, R43.2, SW1.3, SW1.4, SW2.3, SW2.4, T1.2 (E), T2.2 (E), U2.4 (VCC), U3.18 (IOVDD), U3.34 (PVDD), U3.36 (AVDD_2), U3.39 (PLL_MODE1), U3.48 (AVDD), U4.18 (IOVDD), U4.34 (PVDD), U4.36 (AVDD_2), U4.39 (PLL_MODE1), U4.48 (AVDD), Y1.P$4 (VCC); also elsewhere on the board
VOUT0_1: C23.+, U3.46 (VOUT0)
VOUT0_2: C53.+, U4.46 (VOUT0)
VOUT1_1: C9.+, U3.45 (VOUT1)
VOUT1_2: C39.+, U4.45 (VOUT1)
VOUT2_1: C30.+, U3.44 (VOUT2)
VOUT2_2: C60.+, U4.44 (VOUT2)
VOUT3_1: C29.+, U3.43 (VOUT3)
VOUT3_2: C59.+, U4.43 (VOUT3)
WP_1: R19.1, U3.21 (CLATCH/WP)
WP_2: R39.1, U4.21 (CLATCH/WP)

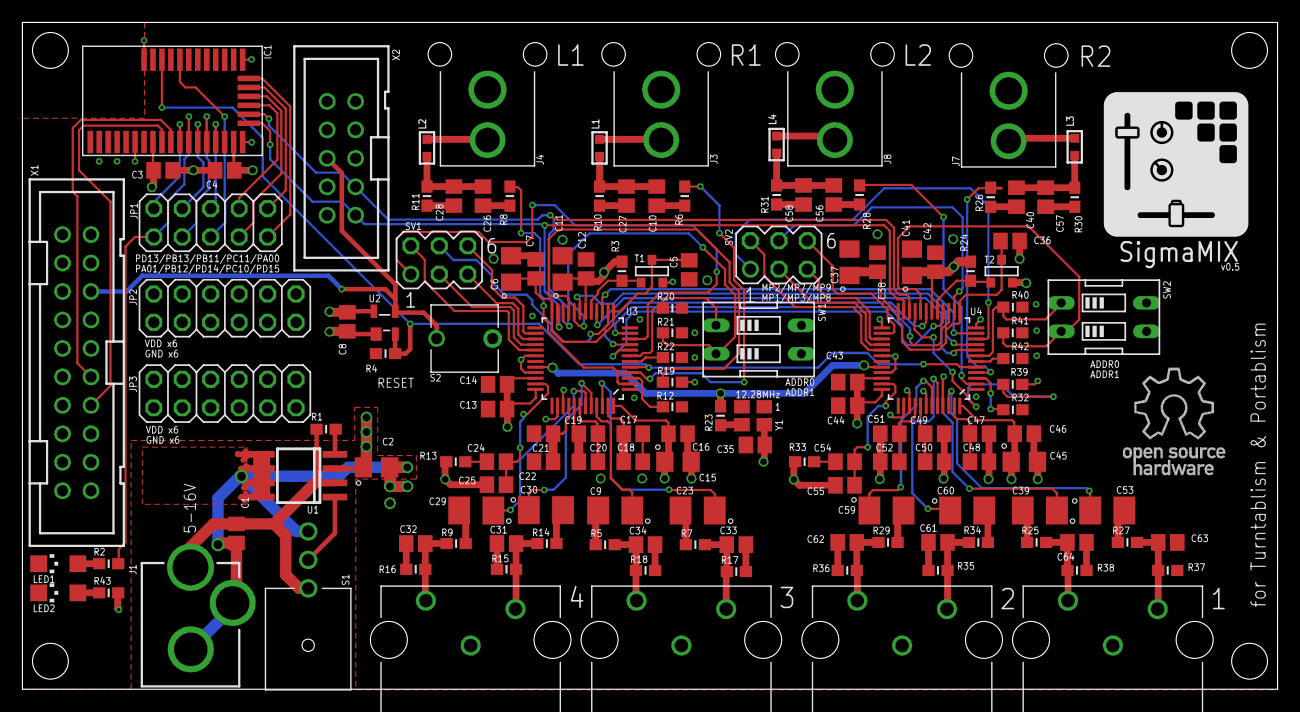
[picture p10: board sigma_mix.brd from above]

Board: 4 copper layers, 112.0 x 59.5 mm, 141 parts (0 on the bottom side), 107 nets.

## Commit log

2017-04-19 Add eagle files.
    [sigma_mix.brd, sigma_mix.sch]
2017-04-19 Add gerber files.
2017-04-19 add schematic pdfs.
2017-04-19 add board pdf.
2017-04-19 Add part list.
    [sigma_mix_partlist.xlsx]
2017-04-19 Add board image.
2017-04-26 Add part No. and Change xtal.
    [sigma_mix_partlist.xlsx]
2017-04-26 Add BOM and update part list.
    [sigma_mix_bom.xlsx, sigma_mix_partlist.xlsx]
2017-04-26 Add mount data.
2017-05-07 Release ver0.2.
    Fixed some bugs of issue.
    [sigma_mix.brd, sigma_mix.sch]
2017-05-15 Release ver0.3.
    Fixed the issue #11, #12, #13.
    Fixed some silk positions.
    [sigma_mix.brd]
2017-05-15 Release ver0.3.
    [sigma_mix_bom.xlsx]
2017-05-15 Add the PCB picture.
2017-06-08 Reseale ver 0.4.
    Fxed the issues #14, #15, #16 and #18.
    [sigma_mix.brd, sigma_mix.sch]
2017-06-09 Update ver 0.4.
    [sigma_mix_bom.xlsx, sigma_mix_partlist.xlsx]
2017-06-22 Add the AutoCAD LT 2018 DWG and PDF.
    [SigmaMIX_Jig.dwg]
2017-06-29 Update to v0.5.
    [sigma_mix_bom.xlsx, sigma_mix_partlist.xlsx]
2017-08-03 Update the BOM and parts list.
    [SigmaMIX_Jig.dwg, sigma_mix_bom.xlsx, sigma_mix_partlist.xlsx]
2017-08-03 Revert "Update the BOM and parts list."
    This reverts commit 2f607d859bf7c325c92fad7b5bdf895f4607e224.
    [SigmaMIX_Jig.dwg, sigma_mix_bom.xlsx, sigma_mix_partlist.xlsx]
2017-08-03 Change the jig's height.
    [SigmaMIX_Jig.dwg]

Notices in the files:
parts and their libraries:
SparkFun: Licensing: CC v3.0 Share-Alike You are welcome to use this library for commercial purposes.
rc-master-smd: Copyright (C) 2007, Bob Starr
